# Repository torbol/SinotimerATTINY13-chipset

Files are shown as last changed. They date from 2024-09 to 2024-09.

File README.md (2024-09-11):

# Introducción

Por necesidad y urgencia se decidió adquirir por Aliexpress un protector de sobretensiones transitorias SINOTIMER. Al ver que no se mencionaba ni en la ficha del producto ni en las instrucciones nada referente a si tiene memoria para guardar los ajustes que se establezcan, me decidí a crear un pequeño chip para que en caso de que se fuera la luz por completo, el aparato se reajustara automáticamente.

## Funcionamiento (Idea)

Se supuso ante el peor de los casos que el aparato no contaría con memoria interna, por lo que partí de que la propia alimentación continuada del dispositivo haría que mantuviese los ajustes (253V como máximo de sobretensión, un 10% por encima de la tensión nominal según reglamento de baja tensión, es decir, un 10% de 230V para España). 

Lo que se propone en este proyecto es crear un pequeño chip que se conecte como un pequeño vampiro a los botones del aparato SET y DOWN (ya que queremos bajar la que viene por defecto de 280V a 253V). Para ello se idea el siguiente circuito:

<div align="center">
	
</div>

Como podemos ver cuenta con 3 pines en la zona superior y dos en la inferior, las dos inferiores deberán ir al GND y a la salida de un regulador de voltaje del SINOTIMER que proporcione alimentación de 5V, por ejemplo uno que lo proporciona es el que alimenta el microcontrolador interno del aparato para comprobar las diferencias de tensión y activar relés. El chip aquí presentado es sencillo, consiste en dos optoacopladores que se activarán según una secuencia indicada por nuestro microcontrolador ATTINY13. Esta secuencia solo se ejecutará una única vez al alimentar el aparato (SINOTIMER), luego se bajará la alimentación para que el chip quede en un estado de consumo mínimo.
## Conexiones chip:
<div align="middle">
  
</div>

### Esquemático circuito:
<div align="center">
   
</div>

# Resultado
## Video

https://github.com/user-attachments/assets/8c8c64fe-9294-41ef-b0de-fd418badb5d0

## Resultado final una vez fabricada la pcb
Aunque es una versión anterior sin el tercer pin de arriba (común botones), funciona exactamente igual (va a común del aparato, que debe ser el mismo para todos, solo que al estar el chip aislado por los optoacpoladores, se optó por el nuevo diseño para tener el mínimo impacto en la pcb del microcontrolador del SINOTIMER, de esta manera, es como si pulsásemos los botones nosotros mismos.

https://github.com/user-attachments/assets/2a9f2775-4988-4b48-812e-7c7adac6edf6

# Moraleja de toda esta historia
Finalmente tras haber desarrollado este pequeño sistema, no fue necesario implementarlo, pues el SINOTIMER que recibí sí que cuenta con memoria en caso de que se quede totalmente sin alimentación. Aún así he decidido subir este proyecto pues podría ser muy útil para otros aparatos, por ejemplo un temporizador para una lavadora antigua, juguetes infantiles que cuenten con botonera, como pequeño interruptor para circuitos de mayor voltaje (ya que los extremos de los octoacopladores están totalmente aislados del ATTINY13). En el caso del modelo P817 utilizado para este chip, soporta hasta 35V colector-emisor o 6V emisor-colector (y el aislamiento que aguantan entre Anodo/Catodo - Emisor/Colector es de 5000V por lo que no se estropearía el chip, solo los optoacopladores):

<div align="center">
   
</div>

## Extra: Para mí lo más importante
Para el modo "deep sleep" no encontré mucha información en internet y lo poco que encontraba no me gustaba. Finalmente a partir del datasheet, adapté mi propio código para el ATTINY13A, para más información visita el proyecto [MRE-ATTINY13A-DEEP_SLEEP](https://github.com/torbol/MRE-ATTINY13A-DEEP_SLEEP).

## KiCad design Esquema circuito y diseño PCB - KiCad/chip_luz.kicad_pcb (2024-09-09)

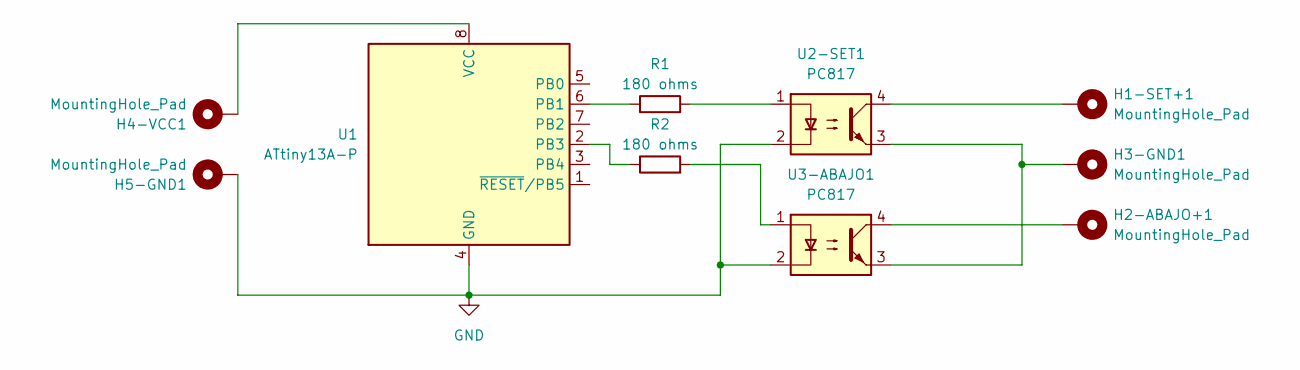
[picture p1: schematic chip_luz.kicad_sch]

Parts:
H1-SET+1, H2-ABAJO+1, H3-GND1, H4-VCC1, H5-GND1: MountingHole_Pad; MountingHole_2.2mm_M2_DIN965_Pad
R1, R2: 180 ohms; R_Axial_DIN0411_L9.9mm_D3.6mm_P12.70mm_Horizontal
U1: ATtiny13A-P; DIP-8_W7.62mm_Socket_LongPads
U2-SET1, U3-ABAJO1: PC817; DIP-4_W7.62mm

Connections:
GND: H5-GND1.1, U1.4 (GND), U2-SET1.2, U3-ABAJO1.2
unnamed: H1-SET+1.1, U2-SET1.4
unnamed: H2-ABAJO+1.1, U3-ABAJO1.4
unnamed: H3-GND1.1, U2-SET1.3, U3-ABAJO1.3
unnamed: R1.2, U2-SET1.1
unnamed: R2.2, U3-ABAJO1.1
unnamed: R1.1, U1.6 (PB1)
unnamed: R2.1, U1.2 (PB3)
unnamed: H4-VCC1.1, U1.8 (VCC)

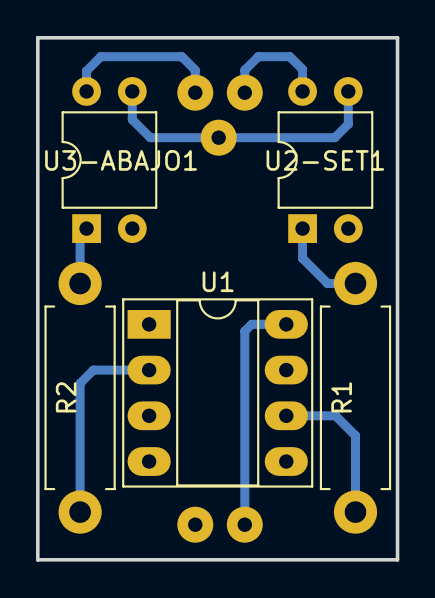
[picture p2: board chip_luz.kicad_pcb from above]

Board: 2 copper layers, 20.0 x 29.0 mm, 10 parts (0 on the bottom side), 9 nets.

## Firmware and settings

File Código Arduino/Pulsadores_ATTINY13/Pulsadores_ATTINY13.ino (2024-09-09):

/* Código para autoconfigurar el ajustador de voltaje 
a 253V como tensión de sobrevoltaje, solo en caso 
de que se vaya completamente la luz en toda su zona
y el aparato se reinicie "perdiendo la configuración"
*/
#define BODCR _SFR_IO8(0x30) //Definimos la dirección de registro directamente de BODCR ya que en el core del ATTINY que estoy usando no lo han definido.

int botonpulsadotime = 300;                   //Tiempo que estará el botón en HIGH
int tiempoesperaentrepulsacion = 300;         //Tiempo delay() entre pulsación botón abajo y despúes de entrar al menú config
int valortensionsubidacorte = 253;            //Se cortará si sube la tensión a 253V ya que es la que se considera subida tensión en reglamento baja tensión (cambiar valor si se desea modificar)- 10% de 230V
int pinset = 1;                               //Indicamos el pin donde estará el set, PB1 (en el datasheet PIN 6)
int pinabajo = 3;                             //Indicamos el pin botón abajo, PB3 (en el datasheet PIN 2)

void setup() {
  //Inicializamos los pines a usar
  pinMode(pinset, OUTPUT); //Este irá al SET
  pinMode(pinabajo, OUTPUT); //Este irá al botón "abajo"


  ////INICIO DEL PROGRAMA - Código que ejecutaremos SOLO al inicio unos segundos después que se haya ido la luz
  delay(15000); //Tiempo que esperamos despúes de reestablecerse la luz para que el aparato esté encendido completamente: 10 segundos
    
  //Presionamos SET para entrar en el menú config
  pulsar(pinset, 4000); //Pasamos el PIN que va al botón SET y se le indica que el primer delay entre HIGH y LOW van a ser 4 segundos (4000ms)
  // Ya estaríamos en P01. Ajuste del valor de tensión por sobrevoltaje

  //Botón abajo
  for (int i = 0; i < 280 - valortensionsubidacorte; i++) { //A 280V que es como viene por defecto en el SINOTIMER se le resta valortensionsubidacorte y obtendremos las veces que tenemos que iterar botón abajo
    //Con este for vamos a simular que estamos pulsando el botón "abajo" para disminuir el valor de sobretensión
    pulsar(pinabajo, botonpulsadotime);
  } // Fin del for para botón "bajar"

  //Finalizamos la configuración pulsando SET hasta llegar a P13 END, por lo que habría que pulsar SET desde P01 que está hasta P13 + 1, es decir hay que pulsarlo 13 veces
  delay(1000);
  for (int i = 1; i <= 13; i++) {
    pulsar(pinset, botonpulsadotime);
  } //Fin for para FINALIZAR config (para llegar a P13)
  ////FIN DEL PROGRAMA

  power_down_mode(); //DORMIR - Dormimos chip con nuestra función
}

void loop() {
}


void pulsar(int PIN, int tiempo) { //Nota: la variable "tiempo" puede ser o un valor entero como 5000 ms o se le puede pasar la variable botonpulsadotime. NOta2: función pulsar(PIN output, tiempoprimerdelay)
  digitalWrite(PIN, HIGH);              // Pulsamos el botón indicado en la variable PIN y lo ponemos en HIGH
  delay(tiempo);                        // Esperamos el tiempo indicado en la variable tiempo
  digitalWrite(PIN, LOW);               // Aquí soltamos el botón indicado en la variable PIN (recuerda 6 para SET y 7 para botón "abajo")
  delay(tiempoesperaentrepulsacion);    // Como su nombre indica es el tiempo que tardaríamos entre pulsación y pulsación
}

void power_down_mode(){ //Función para poner ATTINY13 a dormir profundo para bajar consumo al mínimo (según DATASHEET)
  bitWrite(ACSR,ACD,1); //Deshabilitamos comparador analógico AC para ahorrar energía
  bitWrite(ADCSRA,ADEN,0); //Deshabilita el ADC
  BODCR = B00000010; //Desactiva el Brown-out Detector (BOD) para disminuir consumo
  
  //FUNCIÓN EN C obtenida del DATASHEET para apagar el WATCHDOG TIMER (es como un contador para interrupciones por software en segundos, esto consume energía)
  noInterrupts(); //DORMIR - Esto es para deshabilitar todas las interrupciones y poder deshabilitar el Watchdog timer
  asm("wdr"); //Reset Watchdog Timer
  /* Clear WDRF in MCUSR */
  MCUSR &= ~(1<<WDRF);
  /* Write logical one to WDCE and WDE */
  /* Keep old prescaler setting to prevent unintentional time-out */
  WDTCR |= (1<<WDCE) | (1<<WDE);
  /* Turn off WDT */
  WDTCR = 0x00;
  interrupts();
  //FIN función apagado Watchdog timer (WDT)

  MCUCR = B00110000; //Habilita el modo sleep y define el tipo (power down mode), en este modo el oscilador se para y solo funcionan el Watchdog Timer (si no lo hemos apagado) y las interrupciones externas
  asm("sleep"); //Pone el microcontrolador a dormir
}
